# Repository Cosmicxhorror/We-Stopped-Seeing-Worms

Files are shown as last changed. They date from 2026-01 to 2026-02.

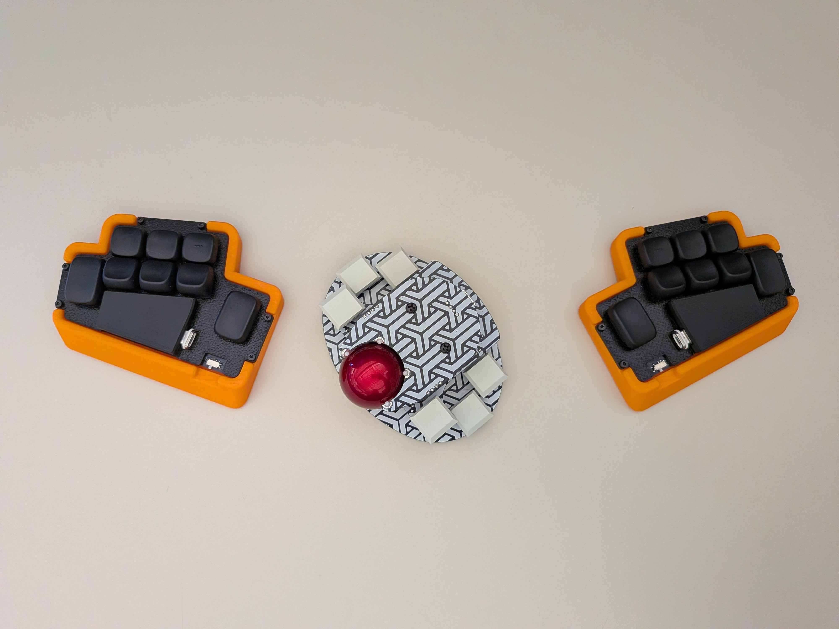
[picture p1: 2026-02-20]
WSSW.jpg

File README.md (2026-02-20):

WSSW is a modified Kunst PCB. I took inspiration from the Kunst, Nine!Nano and the TeenSpirit. 
Main layout is aptmin. 
- Kunst: https://github.com/kunsteak/kunst-keyboard
- Nine!nano: https://github.com/bsag/nine-nano
- TeenSpirit: https://github.com/kilipan/teenspirit
  
## ZMK config: 
https://github.com/Cosmicxhorror/zmk-config-wssw

## Parts list: 
- Power switch x2: Gikfun Micro Slide Switch Toggle Switch SMD On/Off 7 Pin for Arduino (Pack of 20pcs) AE1073
https://a.co/d/0giXDUeh
- Case heat inserts x12: M2x3x3
https://a.co/d/00al3fUf
- Case screws x12: M2x4
https://a.co/d/06F8Wqw6
- Case feet x12: 8mm / 0.3inch Diameter Rubber Dots for Non Slip
https://a.co/d/03dYBlTH
- Choc hotswap sockets x16
- Nice!nano x2
- Battery x2
- Battery conectors x2: JST ZH 1.5 connectors
https://a.co/d/04ykd6lP
-- this is optional as the battery can be soldered direct to the PCB. would like to change this to a standard JST PH 2.0mm in the future

## Battery orientation
- Left side: + - | n!n |USB ->
- Right side: <- USB| n!n |  - +

## Soldering the PCB
The PCB has jumper pads on both sides where the nice!nano can be installed. These jumpers need to be connected with solder on the oposite side of where the n!n is installed. This would be on the same side where the hotswap socket are installed. 

- Example here: BRIDGE THE JUMPER PADS https://kriscables.com/ferris-sweep-build-guide/


Image is of the WSSW with the N7 (negative 7 degree) case. Keycaps are Lamé PBT from aliexpress, had to buy two sets to get the thumb pinky setup for both. Switches are choc v1 Nocturnals. Track ball is a ThumbsUp trackball v3.

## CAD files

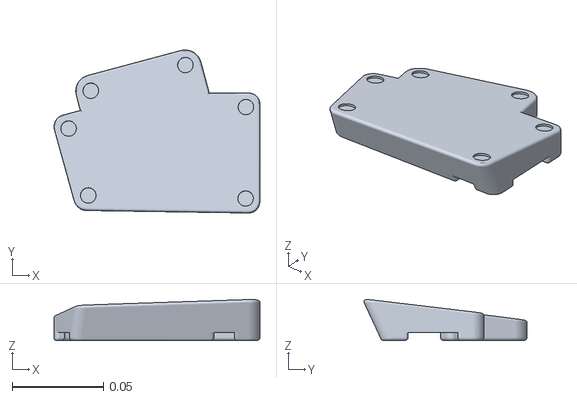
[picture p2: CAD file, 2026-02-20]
wsswBottomN7.stl
0.113 x 0.0891 x 0.0224

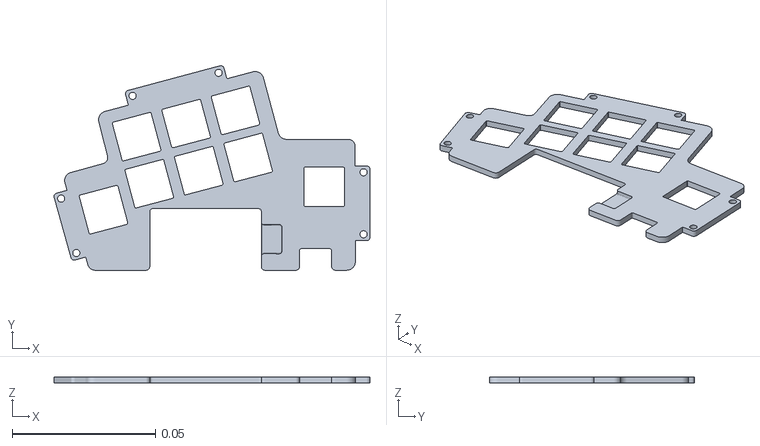
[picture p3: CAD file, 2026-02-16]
wsswPlateShortUSB.stl
0.11 x 0.0714 x 0.0021

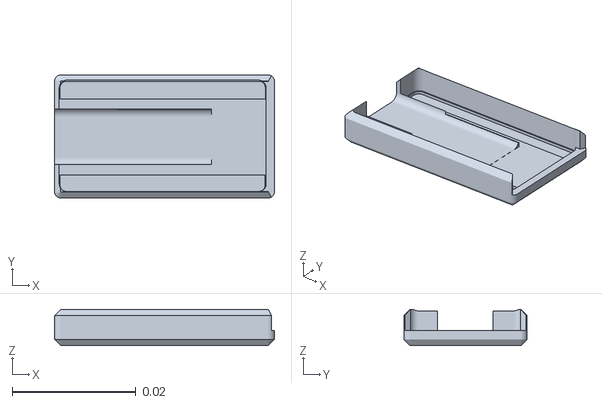
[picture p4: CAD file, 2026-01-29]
nnCover.stl
0.0356 x 0.0199 x 0.00587

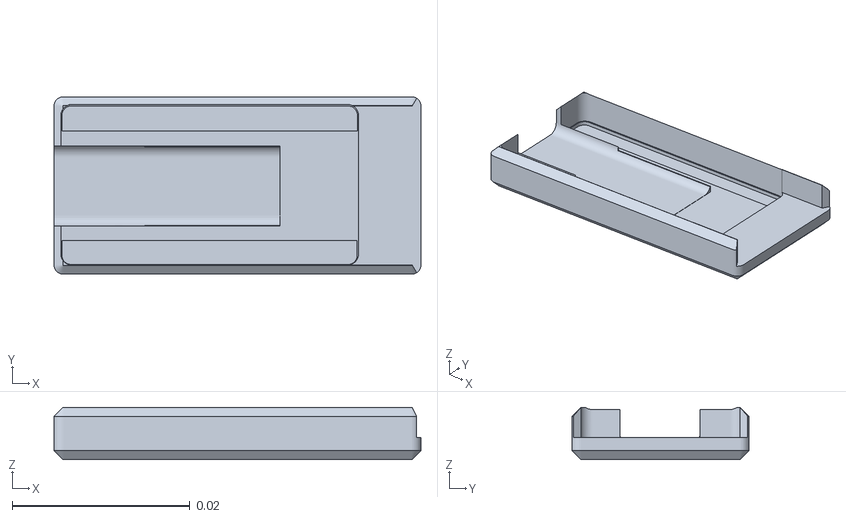
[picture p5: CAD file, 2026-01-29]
nnCoverL.stl
0.0413 x 0.0199 x 0.00587

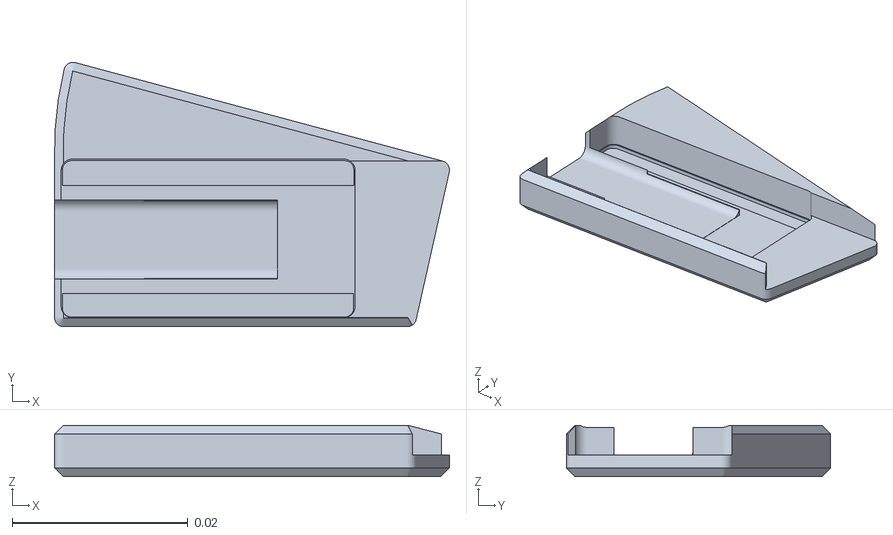
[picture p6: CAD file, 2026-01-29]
nnCoverLW.stl
0.045 x 0.0301 x 0.00587

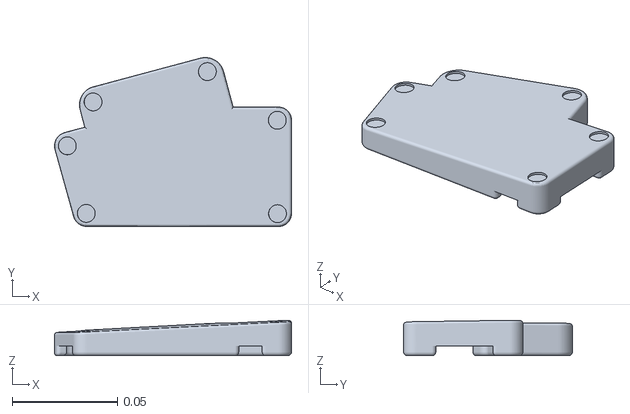
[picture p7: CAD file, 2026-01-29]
WSSWbottom3deg.stl
0.113 x 0.0803 x 0.0168

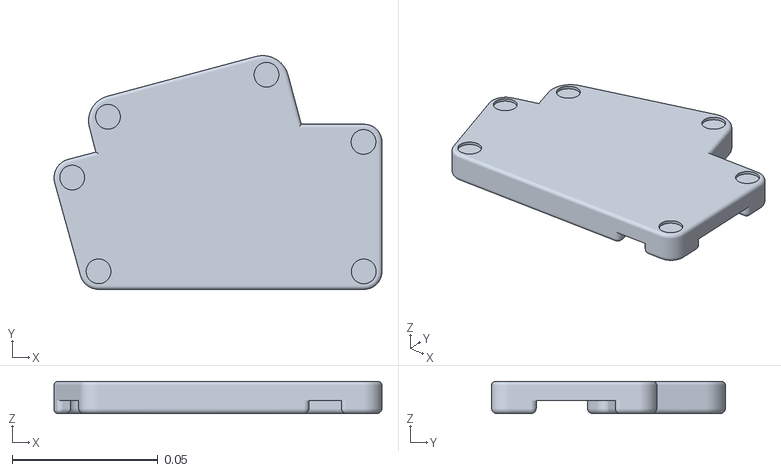
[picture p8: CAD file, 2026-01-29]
WSSWbottomflat.stl
0.113 x 0.0802 x 0.011

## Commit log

2026-01-29 case
    Case files
    [WSSWbottom2.1.stl, WSSWbottom3deg.stl, WSSWbottomflat.stl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]
2026-01-29 PCB Files
2026-01-29 n!n cover variations
    [nnCover.stl, nnCoverL.stl, nnCoverLW.stl]
2026-02-20 Add files via upload
    wssw kicad files
2026-02-20 Create Case
    case files
2026-02-20 KiCad files
    KiCad files
2026-02-20 case
    case
    [wsswPlateShortUSB.stl]
2026-02-20 Fix battery solder orientation formatting
    Correct battery solder orientation formatting in README.
2026-02-20 Fix formatting of optional battery connection note
2026-02-20 Fix typo in battery connectors description
2026-02-20 Update section title and clarify battery orientation
2026-02-20 Add soldering instructions for nice!nano installation
    Added soldering instructions for PCB installation.
2026-02-20 Case step files
    Case step files
2026-02-20 Add image to PCB soldering instructions
    Added an image reference to the soldering section.
